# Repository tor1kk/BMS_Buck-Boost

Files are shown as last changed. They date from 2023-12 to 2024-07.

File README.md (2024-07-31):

# Battery Management System (BMS) with Buck-Boost Converter

## Brief

This Battery Management System (BMS) with Buck-Boost Converter is designed for lithium battery applications, providing a flexible voltage range of 3-5V. 
It is particularly useful in projects requiring stable 3.3V or 5V outputs. The system includes a charging circuit, protection circuit, and a DC-DC buck-boost converter, 
ensuring consistent voltage, enhanced battery safety, and adaptability for various devices.

## Features

The key components of the module include:

- **Charging Circuit:** Utilizing the [MCP73831](https://ww1.microchip.com/downloads/en/DeviceDoc/MCP73831-Family-Data-Sheet-DS20001984H.pdf),
  this circuit facilitates the selection of charge current via a resistor and incorporates an indicator diode.

- **Protection Circuit:** Protection is ensured by [DW01A](https://hmsemi.com/downfile/DW01A.PDF) and [FS8205A](https://datasheet.lcsc.com/lcsc/2010271837_FUXINSEMI-FS8205A_C908265.pdf).
  The FS8205A connects the battery's negative to the common ground, with DW01A controlling battery operation. The transistor disconnects the battery in cases of discharge, overcharge, short circuit, etc.

- **DC-DC Buck-Boost Converter:** Employing [TPS63020DSJR](https://www.ti.com/lit/ds/symlink/tps63020.pdf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),
  this component enables voltage conversion. The goal is to maintain a constant voltage level regardless of the battery charge, acting as a step-up converter when voltage is low and a step-down converter when it's high.

In summary, this module facilitates battery charging, provides protection, and allows for adjustable output voltage.

> Refer to the complete schematic in `BMS_Buck-Boost.pdf`.

## Module Appearance

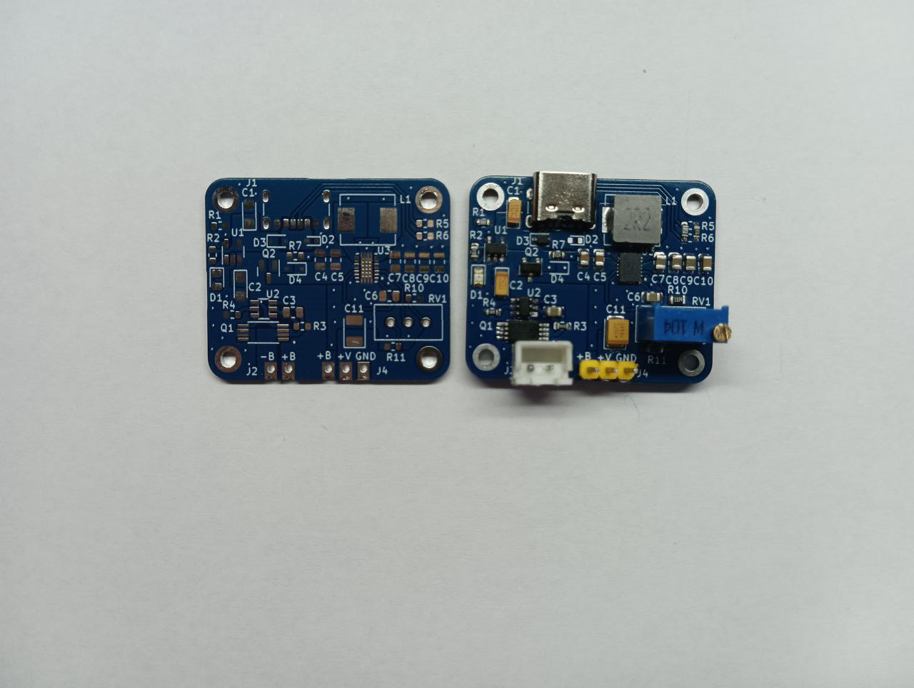
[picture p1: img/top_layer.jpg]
Top Layer

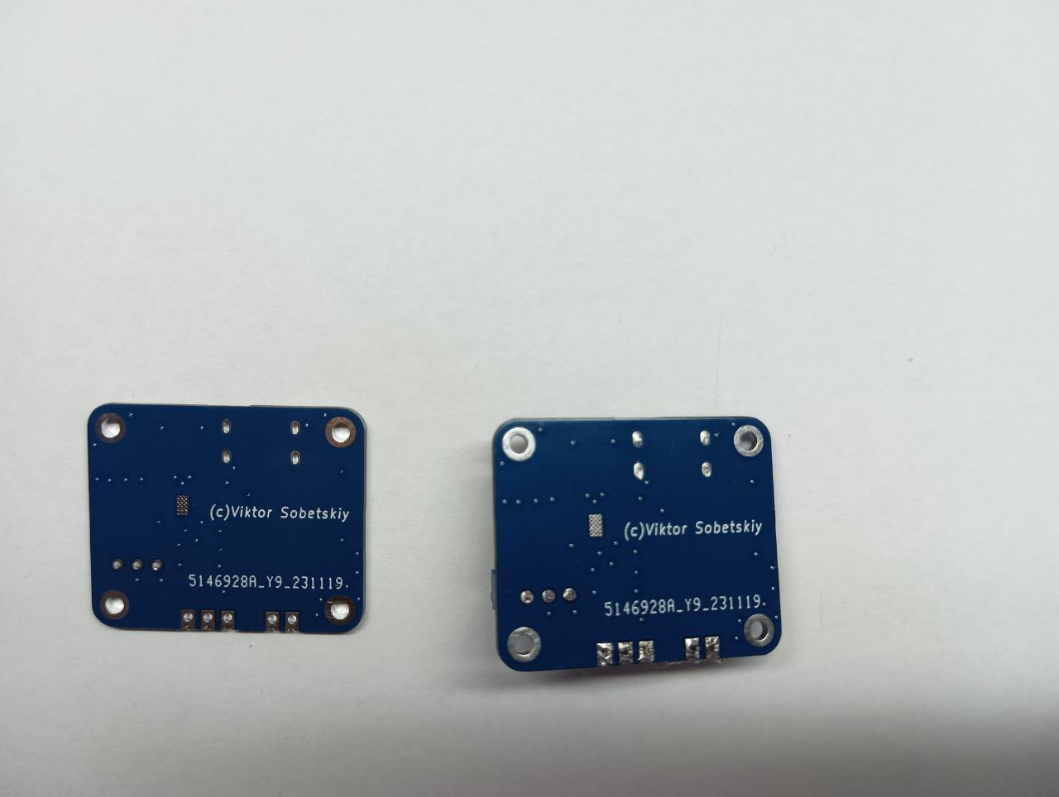
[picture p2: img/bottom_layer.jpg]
Bottom Layer


## Pinouts

- `-B` and `+B` are used to connect the battery.
- `+B`, `+V`, and `GND` are for connecting to the load, with `+B` used for measuring battery voltage.

## Notes

- While using the module during charging and securing the load, certain limitations exist when the level on the `VBUS` line is high. At this point, transistor Q2 (refer to the schematic [here](https://github.com/tor1kk/BMS_Buck-Boost/blob/master/BMS_Buck-Boost.pdf)) doesn't pass the voltage. This is done to optimize battery charge. If you want to use `VBUS` for the DC-DC converter during charging, employ diode `D4` and an additional diode to prevent current from `+VCC_IN` to `+BATT`.

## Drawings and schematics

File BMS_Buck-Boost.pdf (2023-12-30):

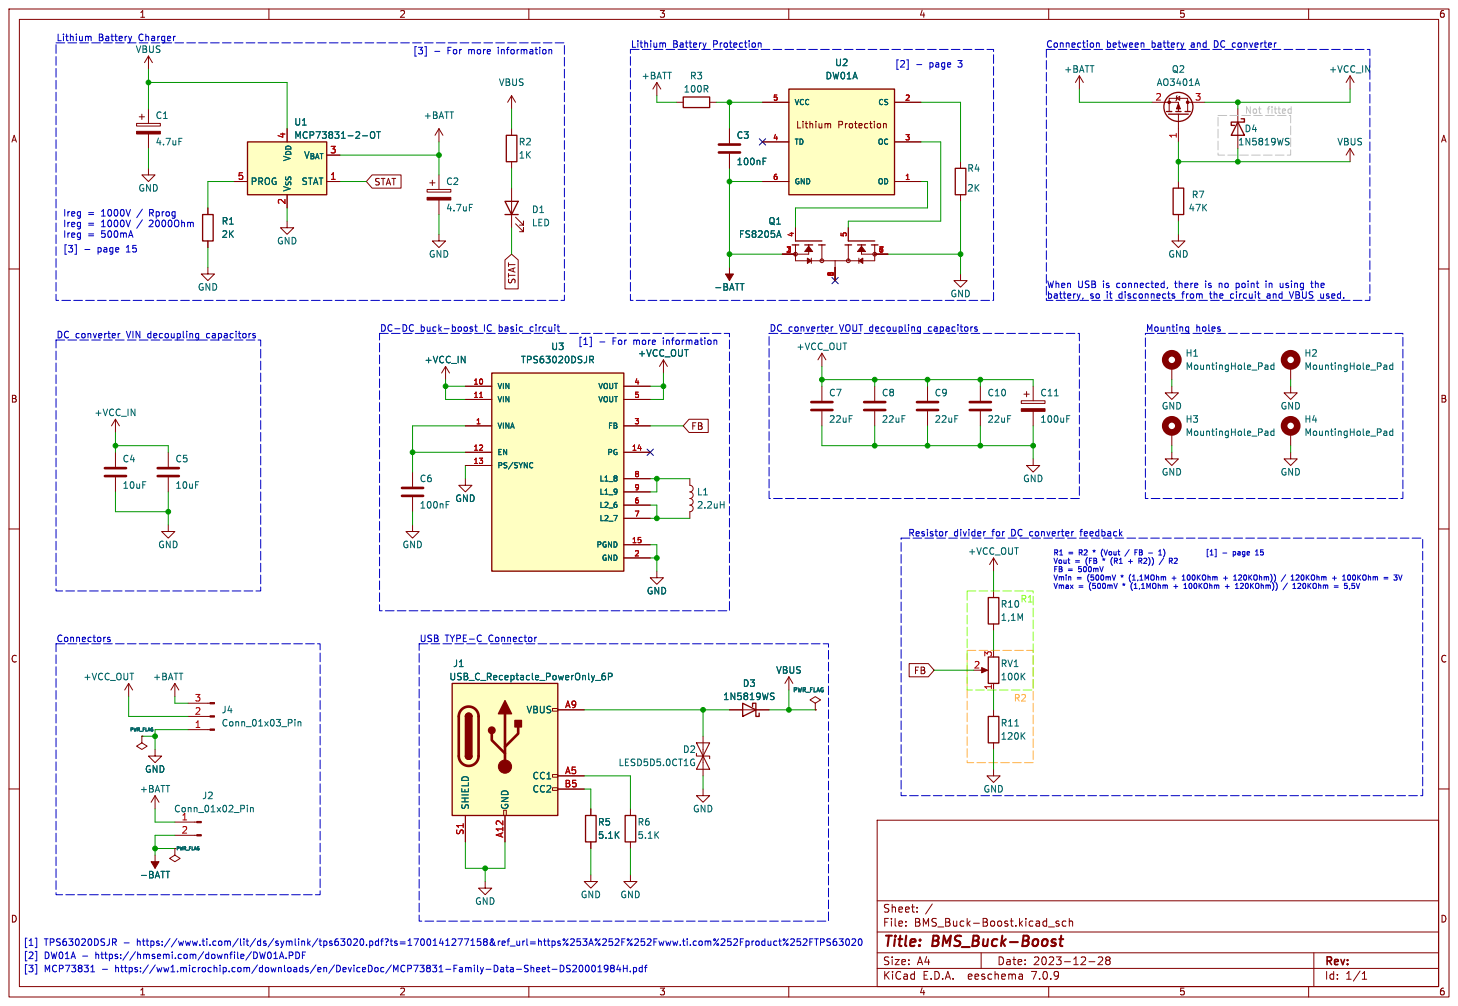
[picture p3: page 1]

Id: 1/1 Title: BMS_Buck-Boost File: BMS_Buck-Boost.kicad_sch Sheet: /

[1] TPS63020DSJR - https://www.ti.com/lit/ds/symlink/tps63020.pdf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

[3] MCP73831 - https://ww1.microchip.com/downloads/en/DeviceDoc/MCP73831-Family-Data-Sheet-DS20001984H.pdf

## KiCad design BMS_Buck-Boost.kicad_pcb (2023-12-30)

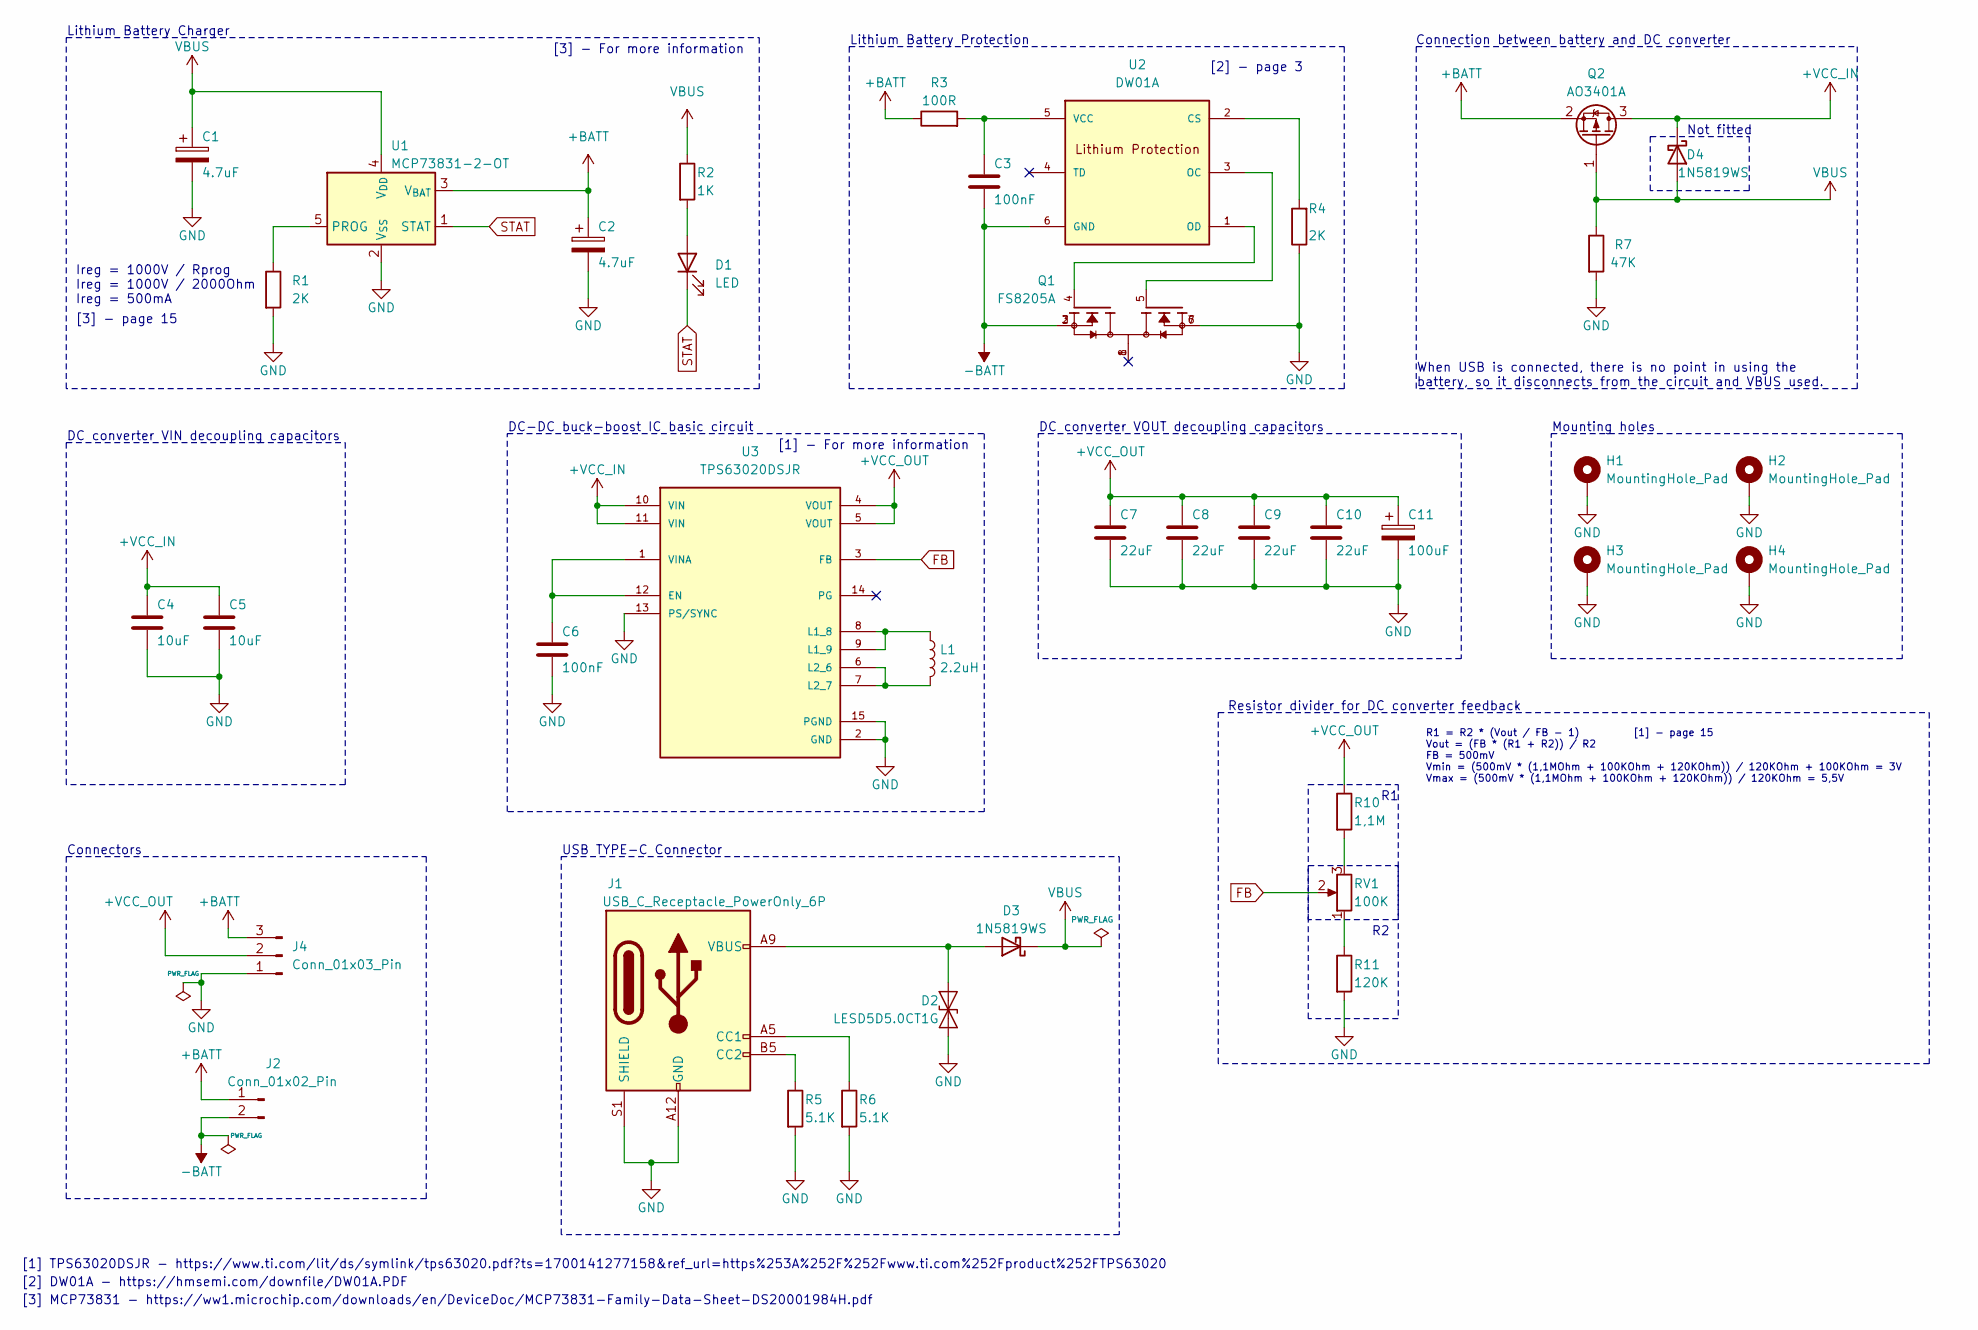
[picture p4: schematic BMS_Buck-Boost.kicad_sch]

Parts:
C1, C2: 4.7uF; CP_EIA-3216-18_Kemet-A
C3, C6: 100nF; C_0805_2012Metric
C4, C5: 10uF; C_0805_2012Metric
C7, C8, C9, C10: 22uF; C_0805_2012Metric
C11: 100uF; CP_EIA-3528-21_Kemet-B
D1: LED; D_0805_2012Metric
D2: LESD5D5.0CT1G; D_SOD-523
D3, D4: 1N5819WS; D_SOD-323F
H1, H2, H3, H4: MountingHole_Pad; MountingHole_2.2mm_M2_DIN965_Pad
J1: USB_C_Receptacle_PowerOnly_6P; USB_C_Receptacle_GCT_USB4125-xx-x-0190_6P_TopMnt_Horizontal
J2: Conn_01x02_Pin; PinSocket_1x02_P2.54mm_Vertical
J4: Conn_01x03_Pin; PinHeader_1x03_P2.54mm_Vertical
L1: 2.2uH; L_Chilisin_BMRx00060630
Q1: FS8205A; SOP65P640X120-8N; PARTREV 1.7
Q2: AO3401A; SOT-23
R1, R4: 2K; R_0603_1608Metric
R2: 1K; R_0603_1608Metric
R3: 100R; R_0603_1608Metric
R5, R6: 5.1K; R_0603_1608Metric
R7: 47K; R_0603_1608Metric
R10: 1,1M; R_0603_1608Metric
R11: 120K; R_0603_1608Metric
RV1: 100K; Potentiometer_Bourns_3296W_Vertical
U1: MCP73831-2-OT; SOT-23-5
U2: DW01A; SOT23-6; M_PART_NUMBER DW01A
U3: TPS63020DSJR; IC_TPS63020DSJR

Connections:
+BATT: C2.1, J2.1, J4.3, Q2.2 (S), R3.1, U1.3 (V_{BAT})
+VCC_IN: C4.1, C5.1, D4.1 (K), Q2.3 (D), U3.10 (VIN), U3.11 (VIN)
+VCC_OUT: C7.1, C8.1, C9.1, C10.1, C11.1, J4.2, R10.1, U3.4 (VOUT), U3.5 (VOUT)
-BATT: C3.2, J2.2, Q1.2, Q1.3, U2.6 (GND)
FB: RV1.2, U3.3 (FB)
GND: C1.2, C2.2, C4.2, C5.2, C6.2, C7.2, C8.2, C9.2, C10.2, C11.2, D2.1 (A1), H1.1, H2.1, H3.1, H4.1, J1.A12 (GND), J1.B12 (GND), J1.S1 (SHIELD), J4.1, Q1.6, Q1.7, R1.2, R4.1, R5.2, R6.2, R7.2, R11.2, U1.2 (V_{SS}), U3.2 (GND), U3.13 (PS/SYNC), U3.15 (PGND)
unnamed: D1.2 (A), R2.2
unnamed: D2.2 (A2), D3.2 (A), J1.A9 (VBUS), J1.B9 (VBUS)
unnamed: J1.A5 (CC1), R6.1
unnamed: J1.B5 (CC2), R5.1
unnamed: R10.2, RV1.3
unnamed: R11.1, RV1.1
unnamed: R1.1, U1.5 (PROG)
unnamed: R4.2, U2.2 (CS)
unnamed: Q1.5, U2.3 (OC)
unnamed: Q1.4, U2.1 (OD)
unnamed: C3.1, R3.2, U2.5 (VCC)
unnamed: C6.1, U3.1 (VINA), U3.12 (EN)
unnamed: L1.1, U3.8 (L1_8), U3.9 (L1_9)
unnamed: L1.2, U3.6 (L2_6), U3.7 (L2_7)
STAT: D1.1 (K), U1.1 (STAT)
VBUS: C1.1, D3.1 (K), D4.2 (A), Q2.1 (G), R2.1, R7.1, U1.4 (V_{DD})

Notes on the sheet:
Mounting holes
[3] - For more information
Resistor divider for DC converter feedback
Not fitted
DC-DC buck-boost IC basic circuit
When USB is connected, there is no point in using the battery, so it disconnects from the circuit and VBUS used.
[1] TPS63020DSJR - https://www.ti.com/lit/ds/symlink/tps63020.pdf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
Ireg = 1000V / Rprog Ireg = 1000V / 2000Ohm Ireg = 500mA
DC converter VOUT decoupling capacitors
[3] - page 15
R1 = R2 * (Vout / FB - 1) [1] - page 15 Vout = (FB * (R1 + R2)) / R2 FB = 500mV Vmin = (500mV * (1,1MOhm + 100KOhm + 120KOhm)) / 120KOhm + 100KOhm = 3V Vmax = (500mV * (1,1MOhm + 100KOhm + 120KOhm)) / 120KOhm = 5,5V
Connectors
[1] - For more information
DC converter VIN decoupling capacitors
Lithium Battery Protection
USB TYPE-C Connector
[3] MCP73831 - https://ww1.microchip.com/downloads/en/DeviceDoc/MCP73831-Family-Data-Sheet-DS20001984H.pdf
Lithium Battery Charger
[2] DW01A - https://hmsemi.com/downfile/DW01A.PDF
Connection between battery and DC converter
[2] - page 3

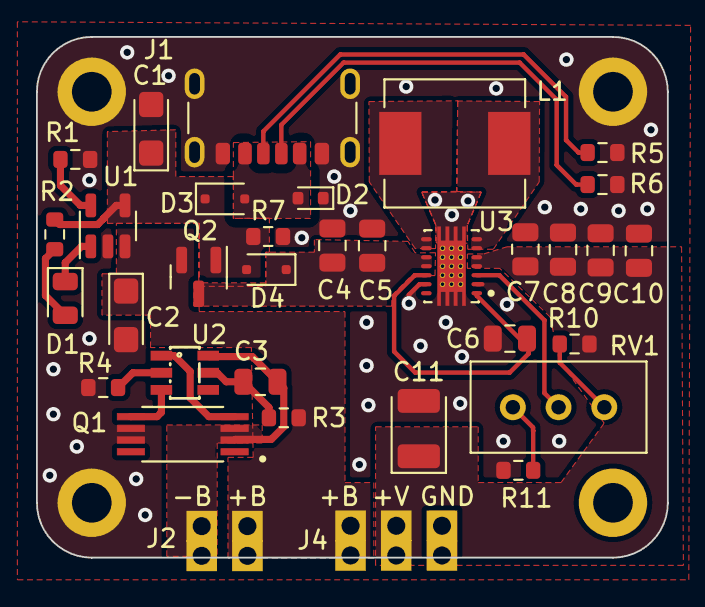
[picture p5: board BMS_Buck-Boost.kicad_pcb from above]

Board: 2 copper layers, 35.1 x 28.9 mm, 38 parts (0 on the bottom side), 22 nets.
